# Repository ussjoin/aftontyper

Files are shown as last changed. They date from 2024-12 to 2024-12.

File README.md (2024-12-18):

# AftonTyper

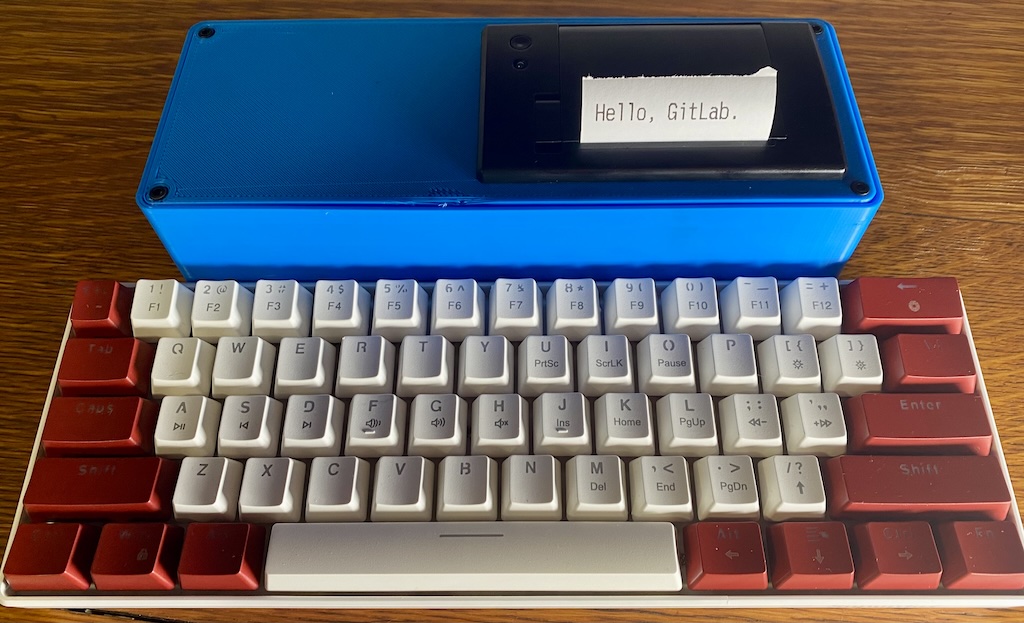
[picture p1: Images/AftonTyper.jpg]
AftonTyper hero image (https://www.youtube.com/watch?v=ykdp6Gb4HfA)

Top view

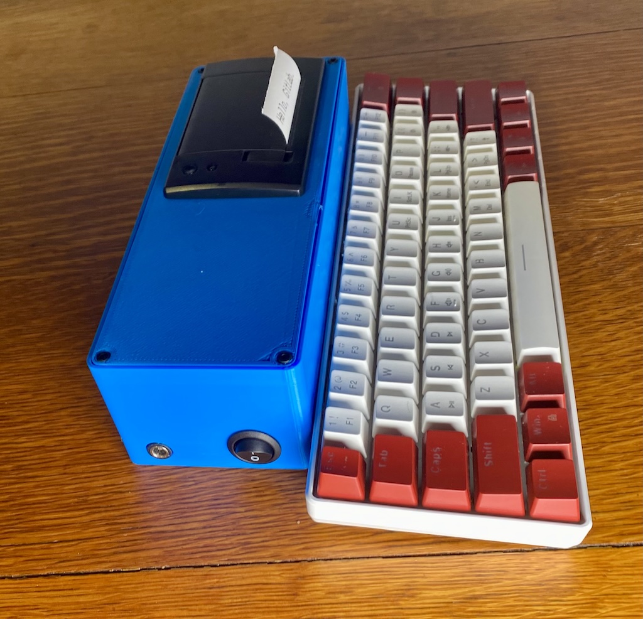
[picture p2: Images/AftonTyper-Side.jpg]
AftonTyper hero image

Side view, showing power switch

## What

For `$reasons`, my (2.5yo) son currently hears and understands spoken language excellently, but speaks only a few words. He speaks increasingly fluent [ASL](https://en.wikipedia.org/wiki/American_Sign_Language). (Yes, he *does* see a ton of experts! They're currently shrugging and waving vaguely at [my son's explosive entry into the world](https://vimeo.com/772624589/0292a5e728) when saying "uh... we don't know why he's doing this, but he sure is a singular child.") 

Long story long, he's now learning to read English before learning to speak English, and he loves to come type on my keyboard. I gave him his own keyboard, but he doesn't like that nothing _happens_ when he types on a keyboard disconnected from everything. So I decided to build him a screenless typing device where he gets output when he provides input.

If he uses this to teach himself to _write_ before he speaks English, well, that'll just be a whole new thing for all the experts to consider. I think they'll [have kittens](https://dictionary.cambridge.org/us/dictionary/english/have-kittens)!

## Components

* Microcontroller: [Adafruit Feather RP2040 with USB Host](https://www.adafruit.com/product/5723). It doesn't need much in the way of brains, but it *does* need a USB host stack. I was worried I'd end up with an ESP32 or something else with overkill performance (and power draw) for this use, but Adafruit has made several "Feather" boards that can take an [add-on USB host board](https://www.adafruit.com/product/5858), but just as I was going to buy it, I came across this all-in-one board. As [the tutorial](https://learn.adafruit.com/adafruit-feather-rp2040-with-usb-type-a-host) notes, "this is definitely a firmware hack: you will need to dedicate the second ARM core and both PIO peripherals to just handling the USB messages." So I probably couldn't run a giant LED matrix or anything, but I'm not.
* Thermal printer: [Adafruit Mini Thermal Receipt Printer](https://www.adafruit.com/product/597). I already had one around that wasn't being used, but if you don't, since Adafruit doesn't stock it anymore, AliExpress has identical ones; search for "mini serial thermal printer" and then look at the photos (in particular, of the wiring/bottom). It runs on anything from 5v-9v.
* Battery: [Bioenno 6v LFP](https://www.bioennopower.com/products/6v-3ah-lfp-battery-charger). I needed something to provide 5v-9v to the printer that I could also use to provide power to the Feather. The feather has an onboard LiPo charger, but only for 3.7v, and they specifically do not recommend powering it via pins or anything *other* than the LiPo port or the USB port. So I decided on the USB with the next device.
* Voltage Converter (for microcontroller): [Adafruit Verter](https://www.adafruit.com/product/2190). Perfect for this because it can supply a steady 5v across the entire range of a 6v (nominal) LFP battery. Could there be a more elegant solution? Sure, but this does what it says on the tin and I'm not trying to source giant amps out of it, so it works wonderfully and reliably.
* Power switch: I thought I had a rocker power switch in a junk drawer, but couldn't find it. I used [this one from Amazon](https://www.amazon.com/dp/B07S1MV462) but use whatever you have laying around; all that matters is that you know the size of hole it wants to sit in. (In this case, 20mm.)
* Keyboard: I wanted USB (so it doesn't have a separate battery to charge), a 60% layout (so it's relatively small to carry around), mechanical (so it feels cool), and relatively inexpensive. I actually didn't want an LED backlight, but I _could not find a 60% keyboard that didn't have backlights_ so whatever. I settled on [this one from Amazon](https://www.amazon.com/gp/product/B0BZTW2S9P/) but anything will do.
* 3D printed: [zx82net Parametric Project Box](https://www.printables.com/model/60749-universal-parametric-project-box). I opened it in [Fusion 360](https://www.autodesk.com/products/fusion-360/personal), adjusted its parameters to what I needed, then cut the extra holes I needed (for power input, power switch, printer, and screws) and printed it on my [Creality Ender 5 Pro](https://www.creality.com/products/ender-5-pro-3d-printer). It's not a great 3D printer, but 1) I got it years ago and it still works, and 2) the point is you don't *need* an incredible thermal printer to do this. I printed it in PLA because that's all I ever use.
* Screws: I used short M2.5 machine screws, washers, and nuts to attach the 3D printed box to the keyboard (I just popped the number keys off the keyboard and then drilled attachment holes). The holes in the 3D-printed box could have been smaller, but then the alignment would have been tighter; this works sufficiently for my needs. (You definitely don't want to glue it, because toddler toy; it's entirely possible I'll need to print another box in a few months depending on how hard it gets dropped.) The screw holes are positioned with the intent that the keyboard and box share the same bottom plane, just to avoid balance issues.

The Bioenno battery comes with its power output terminals crimped in [Anderson Powerpole](), but if that's not a format you like, just pop the contacts out of the plug, cut, and do something else that makes you happier.

## How to Run

You need the Arduino environment, and then you need to add a bunch of board types and libraries to it. The header of [Arduino/aftontyper/aftontyper.ino](Arduino/aftontyper/aftontyper.ino) has all the details to the level of "click here, then there." You'll need to make sure that [Arduino/aftontyper/usbh_helper.h](Arduino/aftontyper/usbh_helper.h) is in the same folder as the `.ino`.

Compile, upload to board, plug it in. You can run the board and keyboard just fine from standard USB power and don't need to use the Verter module for testing (other than testing the power supply). The thermal printer you can run direct from the battery (which is what I do in production) or from a 6v-9v bench power supply; note that when printing wide dark lines, **it peaks over 2A of instantaneous current** (around 2.2A I think), so make sure your supply can handle that.

### Wiring Diagram

It's pretty self-explanatory, but here's what I did.
Note that the RP2040 pins are just set in code; they're not special pins of any kind. Change them with the appropriate lines in the `.ino` file.

```
  ┌─────────────────┐
  │ Thermal Printer │  ┌──────────────────────┐
  │ Comms       Pow │  │       ┌────────────┐ │
  ├─────┐     ┌─────┤  │       │ 6v Battery │ │
  │T R G│     │ + - │  │       │ +       -  │ │
  └┬─┬─┬┴─────┴─┬─┬─┘  │       └─┬───────┬──┘ │
   │ │ │        │ └────┘  ┌──────┴─┐     ├────┘
   │ │ │        └───────┬─┤ Switch │     │
   │ │ │                │ └────────┘     │
   │ │ └──────────┐     │                │┌────────────┬─┐
   │ └───────┐    │     │                └┤-           │U│
   └────┐    │    │     │                 │   Verter   │S├─┐
        │    │    │     └─────────────────┤+           │B│ │
  ┌───┬─┴────┴────┴─┬────┐                └────────────┴─┘ │
  │ U │ 24   25   G │  H │                                 │
┌─┤ S │             │U o │   ┌──────────┐                  │
│ │ B │   RP 2040   │S s ├───┤ Keyboard │                  │
│ │ C │   Feather   │B t │   └──────────┘                  │
│ └───┴─────────────┴────┘                                 │
└──────────────────────────────────────────────────────────┘
```

(Thanks, [ASCIIflow](https://asciiflow.com/)!)

## Features

* "Debouncing" to prevent hitting a capital and a lowercase of the same letter, every time, due to how it processes incoming keys. (That's what `comparator` is doing in the code.)
* Multiple spacebar invocations are combined to one, and it trims spaces off the ends of lines when excreting lines.
* Automatically spits out a line to the printer when the buffer gets full (length set in `buffer_length`). If you change the font size or typeface, you'll probably want to adjust this so that the lines are "full" looking.

Other than that, very little. This is mostly a proof of how little it takes since Adafruit did all the hard work (both in making the microcontroller, and then in making the demo code), and I am very grateful to them. :-) Buy their stuff!

## License

MIT because ~70% of the code is Adafruit's MIT'd example code that I cut down, and I don't want to cause license incompatibilities.

## Where?

"Wait, don't you work for GitLab? Why is this here?" You're right; I wanted to put it on GitLab, but I [couldn't get a formal confirmation](https://gitlab.com/gitlab-com/content-sites/handbook/-/merge_requests/10700) that the (standard) IP assignment that GitLab uses wouldn't eat personal IP like this. So it's here!

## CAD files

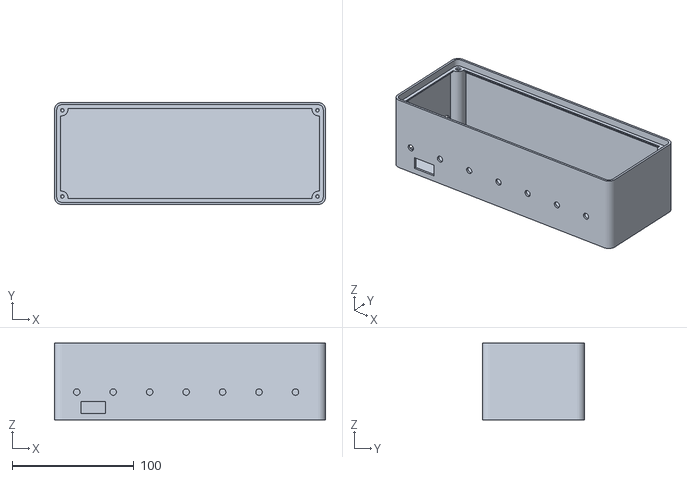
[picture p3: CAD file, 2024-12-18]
Case/Box Bottom.stl
223.0 x 84.0 x 63.0

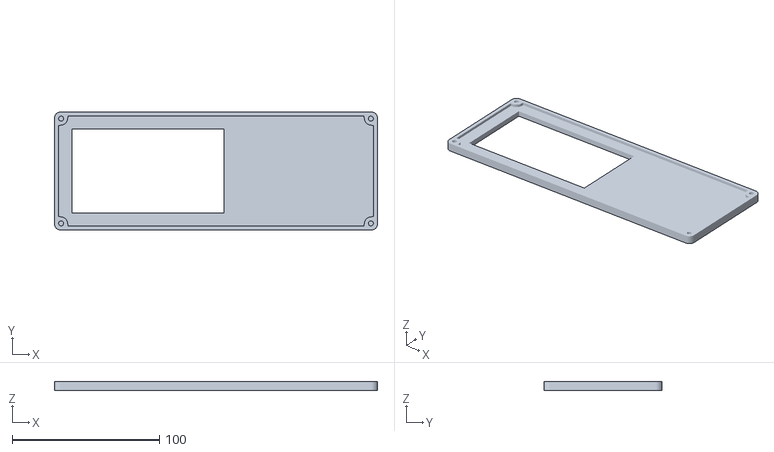
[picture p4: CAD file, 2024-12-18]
Case/Box Lid.stl
219.0 x 80.0 x 6.00

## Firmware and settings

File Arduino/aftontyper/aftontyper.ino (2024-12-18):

// From https://learn.adafruit.com/adafruit-feather-rp2040-with-usb-type-a-host/arduino-ide-setup
// Boards manager URLs in Settings: add https://github.com/earlephilhower/arduino-pico/releases/download/global/package_rp2040_index.json
// Boards Manager: add Raspberry Pi Pico/RP2040/RP2350 by Earle F Philhower, III
// Tools -> Board -> RasPi Pico / RP2040 -> Adafruit Feather RP2040 USB Host

// From https://learn.adafruit.com/adafruit-feather-rp2040-with-usb-type-a-host/usb-host-device-info
// Sketch -> Include Library -> Manage Libraries: Install each of Adafruit TinyUSB, Pico PIO USB, Adafruit Thermal Printer Library
// Tools -> CPU Speed -> 120MHz
// Tools -> USB Stack -> Adafruit TinyUSB

// Much of the below shamelessly stolen from https://github.com/adafruit/Adafruit_TinyUSB_Arduino/blob/master/examples/DualRole/HID/hid_remapper/hid_remapper.ino
// All changes (c) 2024 Brendan O'Connor, licensed MIT for compatibility
// All that code's license:

/*********************************************************************
 Adafruit invests time and resources providing this open source code,
 please support Adafruit and open-source hardware by purchasing
 products from Adafruit!

 MIT license, check LICENSE for more information
 Copyright (c) 2019 Ha Thach for Adafruit Industries
 All text above, and the splash screen below must be included in
 any redistribution
*********************************************************************/

/* This example demonstrates use of both device and host, where
 * - Device run on native usb controller (roothub port0)
 * - Host depending on MCUs run on either:
 *   - rp2040: bit-banging 2 GPIOs with the help of Pico-PIO-USB library (roothub port1)
 *
 * Requirements:
 * - For rp2040:
 *   - [Pico-PIO-USB](https://github.com/sekigon-gonnoc/Pico-PIO-USB) library
 *   - 2 consecutive GPIOs: D+ is defined by PIN_USB_HOST_DP, D- = D+ +1
 *   - Provide VBus (5v) and GND for peripheral
 *   - CPU Speed must be either 120 or 240 Mhz. Selected via "Menu -> CPU Speed"
 */

// USBHost is defined in usbh_helper.h
#include "usbh_helper.h"
// Naturally, from the Adafruit Thermal Printer library.
#include "Adafruit_Thermal.h"

#include "SoftwareSerial.h"
#define TX_PIN 25 // Arduino transmit  YELLOW WIRE  labeled RX on printer
#define RX_PIN 24 // Arduino receive   GREEN WIRE   labeled TX on printer
SoftwareSerial mySerial(RX_PIN, TX_PIN); // Declare SoftwareSerial obj first
Adafruit_Thermal printer(&mySerial);     // Pass addr to printer constructor

bool PLEASE_PRINT = false;

void setup() {
  Serial.begin(115200);

  mySerial.begin(19200);  // Initialize SoftwareSerial for printer
  printer.begin();        // Init printer (same regardless of serial type)

#if defined(CFG_TUH_MAX3421) && CFG_TUH_MAX3421
  // init host stack on controller (rhport) 1
  // For rp2040: this is called in core1's setup1()
  USBHost.begin(1);
#endif

  Serial.println("Hackertyper");
}

#if defined(CFG_TUH_MAX3421) && CFG_TUH_MAX3421
//--------------------------------------------------------------------+
// Using Host shield MAX3421E controller
//--------------------------------------------------------------------+
void loop() {
  USBHost.task();
}

#elif defined(ARDUINO_ARCH_RP2040)
//--------------------------------------------------------------------+
// For RP2040 use both core0 for device stack, core1 for host stack
//--------------------------------------------------------------------+

void loop() {
  // nothing to do
  if (PLEASE_PRINT)
  {
    wicked_printme();
    PLEASE_PRINT = false;
  }
}

//------------- Core1 -------------//
void setup1() {
  // configure pio-usb: defined in usbh_helper.h
  rp2040_configure_pio_usb();

  //Initialize the printer buffer
  clear_buffer();

  // run host stack on controller (rhport) 1
  // Note: For rp2040 pico-pio-usb, calling USBHost.begin() on core1 will have most of the
  // host bit-banging processing works done in core1 to free up core0 for other works
  USBHost.begin(1);
}

void loop1() {
  USBHost.task();
}
#endif

//--------------------------------------------------------------------+
// TinyUSB Host callbacks
//--------------------------------------------------------------------+
extern "C"
{
  // Invoked when device with hid interface is mounted
  // Report descriptor is also available for use.
  // tuh_hid_parse_report_descriptor() can be used to parse common/simple enough
  // descriptor. Note: if report descriptor length > CFG_TUH_ENUMERATION_BUFSIZE,
  // it will be skipped therefore report_desc = NULL, desc_len = 0
  void tuh_hid_mount_cb(uint8_t dev_addr, uint8_t instance, uint8_t const *desc_report, uint16_t desc_len) {
    (void) desc_report;
    (void) desc_len;
    uint16_t vid, pid;
    tuh_vid_pid_get(dev_addr, &vid, &pid);

    Serial.printf("HID device address = %d, instance = %d is mounted\r\n", dev_addr, instance);
    Serial.printf("VID = %04x, PID = %04x\r\n", vid, pid);

    uint8_t const itf_protocol = tuh_hid_interface_protocol(dev_addr, instance);
    if (itf_protocol == HID_ITF_PROTOCOL_KEYBOARD) {
      Serial.printf("HID Keyboard\r\n");
      if (!tuh_hid_receive_report(dev_addr, instance)) {
        Serial.printf("Error: cannot request to receive report\r\n");
      }
    }
  }

  // Invoked when device with hid interface is un-mounted
  void tuh_hid_umount_cb(uint8_t dev_addr, uint8_t instance) {
    Serial.printf("HID device address = %d, instance = %d is unmounted\r\n", dev_addr, instance);
  }

  // Key data: https://github.com/hathach/tinyusb/blob/master/src/class/hid/hid.h#L1112
  uint8_t const conv_table[128][2] =  { HID_KEYCODE_TO_ASCII };
  uint8_t const buffer_length = 15;
  char printing_buffer[buffer_length+1];
  char last_unshifted;
  uint8_t printing_index = 0;
  unsigned long last_time;

  char actual_output_buffer[buffer_length+1];

  void clear_buffer()
  {
    for (uint8_t i = 0; i < buffer_length+1; i++)
    {
      printing_buffer[i] = 0;
    }
    printing_index = 0;

    //Set up initial key debounce time
    last_time = micros();
    last_unshifted = '0';
  }

  void wicked_printme()
  {
    printer.wake();       // MUST wake() before printing again, even if reset
    // Font options
    printer.setFont('A');
    printer.setSize('L');        // Set type size, accepts 'S', 'M', 'L'

    printer.println(actual_output_buffer);
    
    // Send it to Arduino IDE as well
    Serial.println("ACTUALLY PRINTING:");
    Serial.println(actual_output_buffer);
    Serial.println();
    // Put printer to sleep (after a print)
    printer.sleep();
  }

  void wicked_buffer(hid_keyboard_report_t const *original_report) {
    for (uint8_t i = 0; i < 6; i++) {
      // only add to buffer if not empty report i.e key released
      if (original_report->keycode[i] != 0) {
        char comparator = conv_table[original_report->keycode[i]][0];

        // TODO: Debouncing here would be nice (mostly around shift key)
        if (comparator == last_unshifted)
        {
          // https://docs.arduino.cc/language-reference/en/functions/time/micros/
          unsigned long the_time = micros();
          if (the_time < last_time || the_time < last_time + 100000)
          {
            // either the_time < last_time (time overflowed) or the delta is < 0.1s
            break; // ignore this key to debounce 
          }
        } 

        bool shift = false;
        if (original_report->modifier == KEYBOARD_MODIFIER_LEFTSHIFT || original_report->modifier == KEYBOARD_MODIFIER_RIGHTSHIFT)
        {
          shift = true;
        }
        char ch = shift ? conv_table[original_report->keycode[i]][1] : conv_table[original_report->keycode[i]][0];

        bool print_now = false;
        // Specialcase Return key
        if (ch == 0x0d) // Carriage Return
        {
          printing_buffer[printing_index] = 0;
          print_now = true;
        }
        else if (ch == 0x20 && printing_index == 0) // Space
        {
          //We don't want leading spaces on lines because they make it look weird.
          break;
        }
        else
        {
          printing_buffer[printing_index] = ch;
          last_unshifted = comparator;
          printing_index++;
          if (printing_index == buffer_length)
          {
            print_now = true;
          }
        }

        last_time = micros();
        last_unshifted = comparator;

        if (print_now)
        {
          strcpy(actual_output_buffer, printing_buffer);
          PLEASE_PRINT = true;
          clear_buffer();
        }
        break;
      }
    }
  }

  // Invoked when received report from device via interrupt endpoint
  void tuh_hid_report_received_cb(uint8_t dev_addr, uint8_t instance, uint8_t const *report, uint16_t len) {
    if (len != 8) {
      Serial.printf("report len = %u NOT 8, probably something wrong !!\r\n", len);
    } else {
      wicked_buffer((hid_keyboard_report_t const *) report);

    }

    // continue to request to receive report
    if (!tuh_hid_receive_report(dev_addr, instance)) {
      Serial.printf("Error: cannot request to receive report\r\n");
    }
  }

}

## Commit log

2024-12-13 Initial commit of code and case.
    [box v3 lid.stl, box v6.stl]
2024-12-14 Wiring diagram.
2024-12-15 Tightening up the wiring diagram.
2024-12-15 Label the thermal printer.
2024-12-18 Updating box STLs.
    [Box Bottom.stl, Box Lid.stl, box v3 lid.stl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]
2024-12-18 Accidentally deleted the printer sleep command, so restored it. Also setting font details on every print to avoid a weird edge case.
    [aftontyper.ino]
